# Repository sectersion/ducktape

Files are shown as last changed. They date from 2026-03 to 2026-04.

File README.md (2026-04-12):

# ducktape

**ducktape** is a budget-friendly, fully open alternative to the USB Rubber ducky, the well-known keystroke-injection tool used in cybersecurity and physical pentesting.  
The goal: COST OPTIMIZATION

Instead of hiding behind proprietary hardware, ducktape uses simple off-the-shelf parts and a dead-simple design you can understand, repair, and modify. Cheap to build, easy to hack on, and perfect for learning physical security without dropping triple digits on a dongle.

I built this because I’m diving deeper into physical access testing, and I refuse to pay luxury-brand prices for tools that are essentially microcontrollers pretending to be premium gear.  
Companies like Flipper and Hak5 make cool stuff — sure — but most of it can be recreated for a fraction of the price if you’re willing to solder and tinker.

## Schematic


## PCB



## 3D Model


## Disclaimer
This project is for **educational and authorized security testing only**.  
You’re responsible for how you use it.  
If you plug this into a device you don’t have explicit permission to test, that’s on you, not me, not the repo, not the PCB.

Pentest ethically.

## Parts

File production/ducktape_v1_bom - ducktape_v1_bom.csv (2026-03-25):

Designator | Footprint | Quantity | Value | LCSC Part #
C1, C2, C8 | 0402 | 3 | 1uF | C14445
C3 | 0402 | 1 | 10uF | C315248
C4, C6, C7 | 0402 | 3 | 100nF | C77020
D1 | LED_WS2812B-2020_PLCC4_2.0x2.0mm | 1 | WS2812B-2020 | C965555
J1 | PinSocket_1x04_P2.54mm_Vertical | 1 | SSD1306 | C2718488
J2 | USB_A_CNCTech_1001-011-01101_Horizontal | 1 | USB_A | C2943127
J3 | USB_C_Receptacle_HRO_TYPE-C-31-M-12 | 1 | USB_C_Receptacle_USB2.0_16P | C165948
J4 | PinHeader_1x02_P2.54mm_Vertical | 1 | ARM | C42431798
R1, R2 | 0402 | 2 | 10k | C60490
R3, R4 | 0402 | 2 | 5.1k | C105872
R5 | 0402 | 1 | 33R | C138002
S1 | SW_SKRPACE010 | 1 | BOOT | C139797
S2 | SW_SKRPACE010 | 1 | EN | C139797
U2 | SOIC127P790X216-8N | 1 | W25Q16JVSSIQ | C131025
U3 | SOT94P279X129-5N | 1 | RT9013-33GB | C47773
U4 | ESP32-S2-MINI-1U | 1 | ESP32-S3-MINI-1U | C2980299

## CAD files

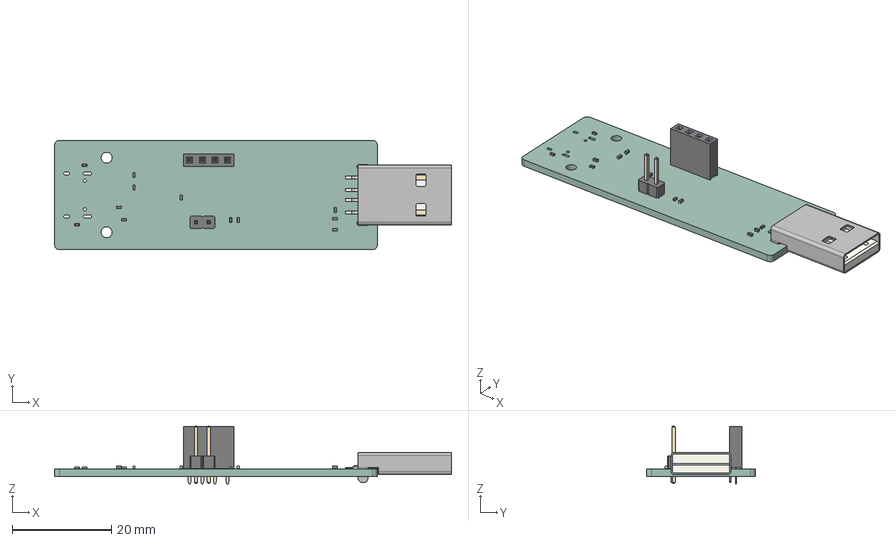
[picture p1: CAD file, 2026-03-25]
ducktape.step
79.9 x 22.0 x 11.6 mm
USB_A_CNCTech_1001-011-01101_Horizontal
C_0402_1005Metric x 7
PinHeader_1x02_P2.54mm_Vertical
R_0402_1005Metric x 5
PinSocket_1x04_P2.54mm_Vertical
ducktape_PCB

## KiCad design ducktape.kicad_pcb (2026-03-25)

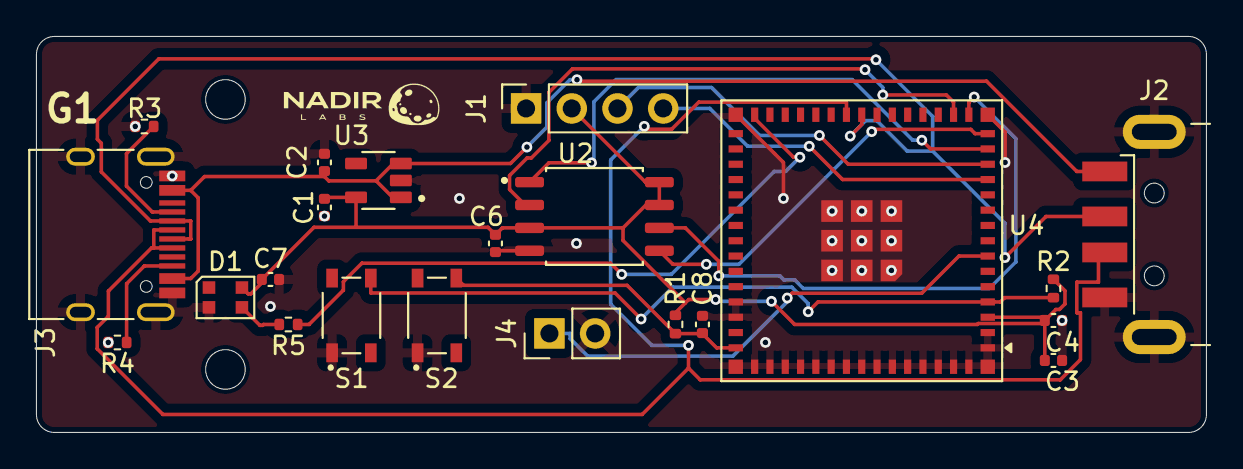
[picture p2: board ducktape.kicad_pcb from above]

Board: 2 copper layers, 65.0 x 22.0 mm, 25 parts (0 on the bottom side), 18 nets.

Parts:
C1, C2, C8: 1uF; C_0402_1005Metric
C3: 10uF; C_0402_1005Metric
C4, C6, C7: 100nF; C_0402_1005Metric
D1: WS2812B-2020; LED_WS2812B-2020_PLCC4_2.0x2.0mm
G1: LOGO; nl_bw
J1: SSD1306; PinSocket_1x04_P2.54mm_Vertical
J2: USB_A; USB_A_CNCTech_1001-011-01101_Horizontal
J3: USB_C_Receptacle_USB2.0_16P; USB_C_Receptacle_HRO_TYPE-C-31-M-12
J4: ARM; PinHeader_1x02_P2.54mm_Vertical
R1, R2: 10k; R_0402_1005Metric
R3, R4: 5.1k; R_0402_1005Metric
R5: 33R; R_0402_1005Metric
REF1, REF1#2: MountingHole_2.2mm_M2
S1: BOOT; SW_SKRPACE010
S2: EN; SW_SKRPACE010
U2: W25Q16JVSSIQ; SOIC127P790X216-8N
U3: RT9013-33GB; SOT94P279X129-5N
U4: ESP32-S3-MINI-1U; ESP32-S2-MINI-1U

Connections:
+3V3: C1.2, C3.2, C4.2, C6.1, C7.1, D1.4 (VDD), J1.2, R1.1, R2.1, U2.3 (~WP(IO2)), U2.7 (~HOLD/RESET(IO3)), U2.8 (VCC), U3.5 (VOUT), U4.3 (3V3)
+5V: C2.2, J2.1 (VBUS), J3.A4 (VBUS), J3.A9 (VBUS), J3.B4 (VBUS), J3.B9 (VBUS), U3.1 (VIN), U3.3 (EN)
/DISP_SCL: J1.3, U4.13 (IO9)
/DISP_SDA: J1.4, U4.12 (IO8)
/FLASH_CLK: U2.6 (CLK), U4.16 (IO12)
/FLASH_CS: U2.1 (~CS), U4.14 (IO10)
/FLASH_MISO: U2.2 (DO(IO1)), U4.17 (IO13)
/FLASH_MOSI: U2.5 (DI(IO0)), U4.15 (IO11)
/RGB_LED: R5.1, U4.30 (IO48)
/USB_DM: J2.2 (D-), J3.A7 (D-), J3.B7 (D-), U4.23 (USB_D-)
/USB_DP: J2.3 (D+), J3.A6 (D+), J3.B6 (D+), U4.24 (USB_D+)
GND: C1.1, C2.1, C3.1, C4.1, C6.2, C7.2, C8.1, D1.2 (VSS), J1.1, J2.4 (GND), J2.5 (Shield), J3.A1 (GND), J3.A12 (GND), J3.B1 (GND), J3.B12 (GND), J3.S1 (SHIELD), J4.2, R3.2, R4.2, S1.1, S2.1, U2.4 (GND), U3.2 (GND), U4.1 (GND), U4.2 (GND), U4.42 (GND), U4.43 (GND), U4.46 (GND), U4.47 (GND), U4.48 (GND), U4.49 (GND), U4.50 (GND), U4.51 (GND), U4.52 (GND), U4.53 (GND), U4.54 (GND), U4.55 (GND), U4.56 (GND), U4.57 (GND), U4.58 (GND), U4.59 (GND), U4.60 (GND), U4.61 (GND), U4.62 (GND), U4.63 (GND), U4.64 (GND), U4.65 (GND)
unnamed: D1.3 (DIN), R5.2
unnamed: J3.A5 (CC1), R3.1
unnamed: J3.B5 (CC2), R4.1
unnamed: J4.1, U4.7 (IO3)
unnamed: C8.2, R1.2, S2.4, U4.45 (EN)
unnamed: R2.2, S1.4, U4.4 (IO0)

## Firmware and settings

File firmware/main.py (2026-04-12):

import pinlayout
from led import update_led
from arm import arm_shorted
from flash import *
from hidkbd import Keyboard
from ducky import run_commands

kb = Keyboard()



def program_mode():
    print("PROGRAM MODE")
    print("Send text over USB serial. End with 'EOF' on its own line.")

    lines = []

    while True:
        try:
            line = input()
        except EOFError:
            continue

        if line == "EOF":
            break

        lines.append(line)

    text = "\n".join(lines)

    print("Clearing flash...")
    clear_chip()

    print("Writing flash...")
    write_all(text)
    print("Done. Rebooting recommended.")




def payload_mode():
    script = read_all()
    run_commands(script, kb)



def main():
    update_led()

    if arm_shorted():
        payload_mode()
    else:
        # Programming mode
        program_mode()


main()

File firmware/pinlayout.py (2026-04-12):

from machine import Pin

# display pin assignments
DISP_SDA = Pin(8)   # data
DISP_SCL = Pin(9)   # clock

#flash pins
FLASH_CS = Pin(10)
FLASH_MOSI = Pin(11)
FLASH_CLK = Pin(12)
FLASH_MISO = Pin(13)

#led
RGB_LED = Pin(48)

#arm header
ARM = Pin(3, Pin.IN, Pin.PULL_UP)

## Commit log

2026-03-23 feat: schematic in one sitting
    [ducktape.kicad_pcb, ducktape.kicad_sch]
2026-03-24 finish pcb and generate gerbers
    [ducktape-B_Cu.gbl, ducktape-B_Mask.gbs, ducktape-B_Paste.gbp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]
2026-03-25 finish PCB and export 3d model
    [ducktape.kicad_pcb, ducktape.step, ducktape_v1_bom - ducktape_v1_bom.csv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]
2026-04-12 Enhance README with schematic and PCB details
    Added schematic and PCB sections with images to README.
